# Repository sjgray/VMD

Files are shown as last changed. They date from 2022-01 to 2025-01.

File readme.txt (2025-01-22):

VMD - Visual Memory Display - Steve J. Gray
===========================

INTRO

This is a fun little project, probably not with many practical uses,
other than being a cool blinking lights display. On the CBM-Hackers
forum Leif Bloomquist proposed the idea of adding interesting lights
inside his transparent C64 case to show computer activity. I came up
with an idea to use a large 16x16 LED matrix wired to the address
bus using some 4-to-16 decoders. Jim Brain liked the idea and said
he would build it, and he did. He came up with a circuit which he
demonstrated at the VCF-MW show in September 2016. I am attempting to
design a PCB or two to implement this internally.

STATUS

The project is functional. This version is the initial proof of concept
design, not created for any specific LED matrix modules. You will need
to look at the datasheet for your module and figure out how to connect
them. The COL pins are the + (anode) of the LED and the ROW are the cathode.

I was hoping to improve the design, and/or adapt it to some specific LED
module to make connections easier, but the project seems to have been
put on the back-burner. So, I am releasing the schematics and gerbers
as-is in the hopes that it might be useful.

FOLDERS

VMD.......... Main Visual Memory Display board
CPU-Tap...... 6502/6510 breakout board with VMD connectors.
		tabs can be removed if you just need the breakout pins.
MemoryMaps... Memory Maps for CBM computers using 16x16 matrix organization

WEB

You can find more info on the project webpage:

http://www.cbmsteve.ca/
http://www.cbmsteve.ca/vmd/index.html

Steve

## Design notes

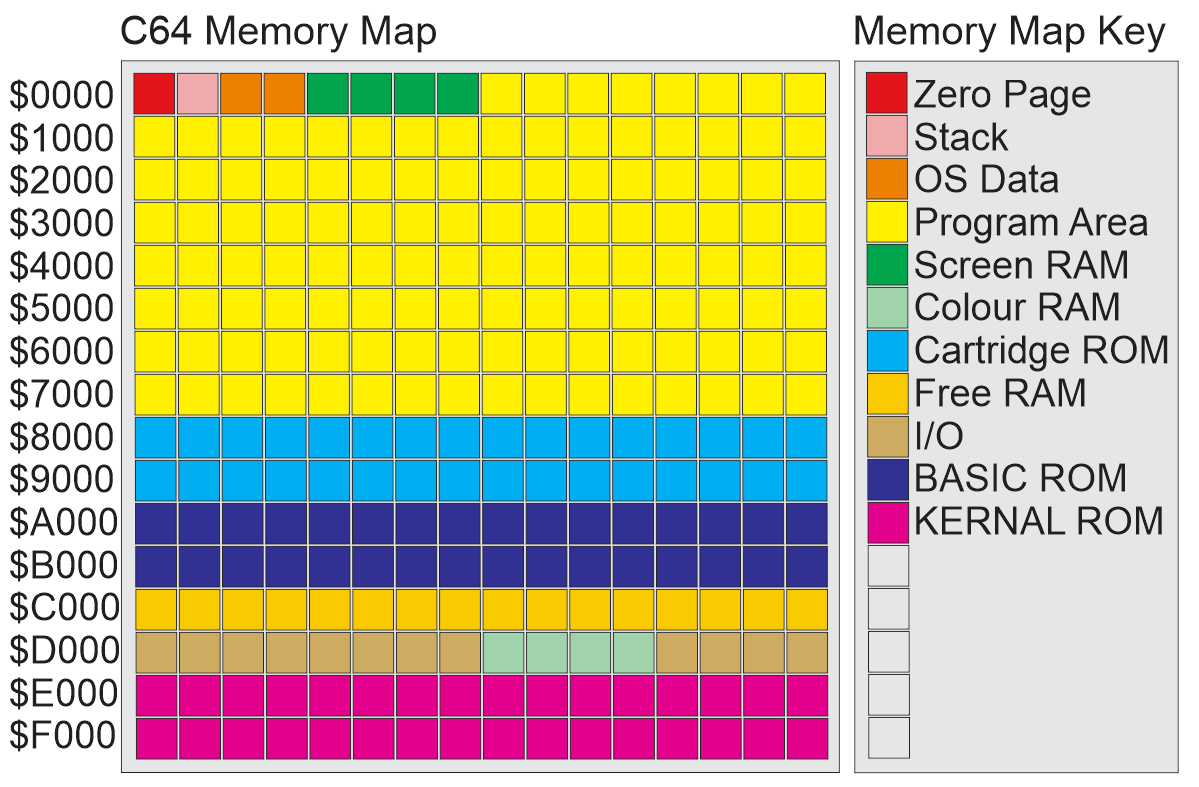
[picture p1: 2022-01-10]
MemoryMaps/vmd-map-c64.png

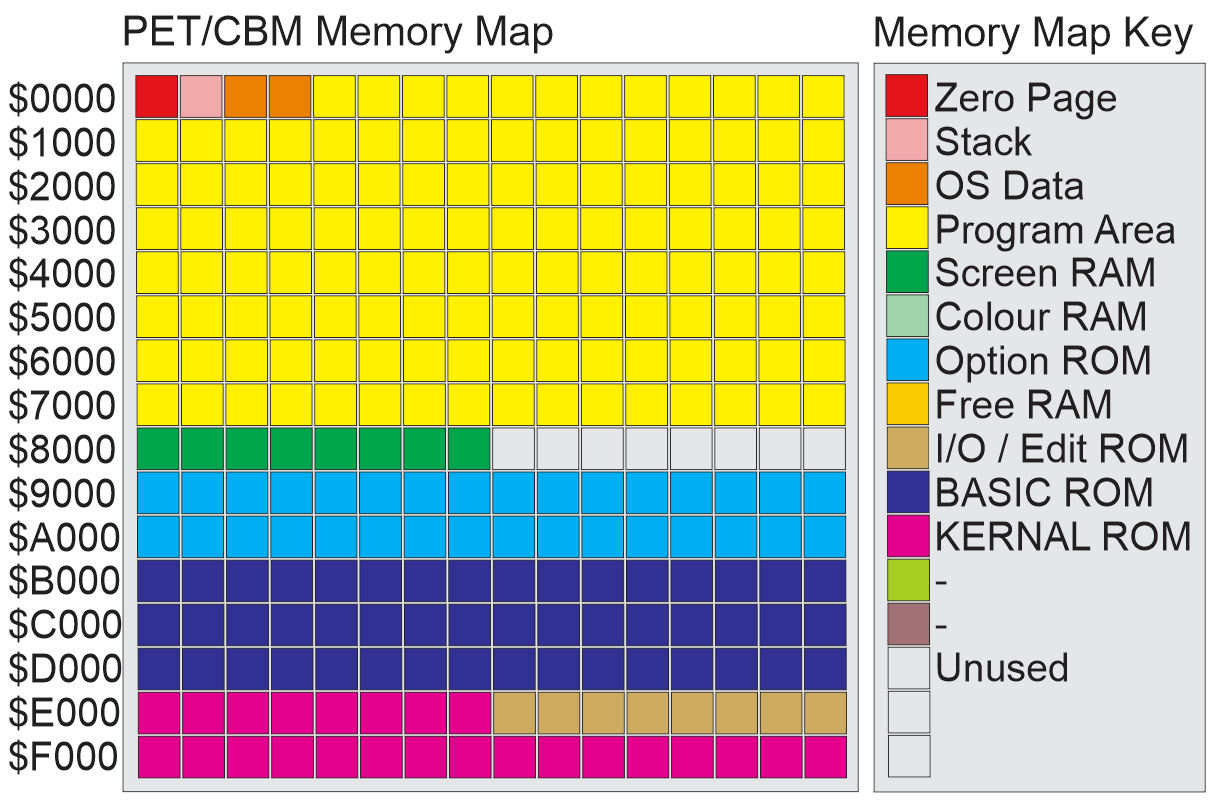
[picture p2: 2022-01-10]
MemoryMaps/vmd-map-pet.png

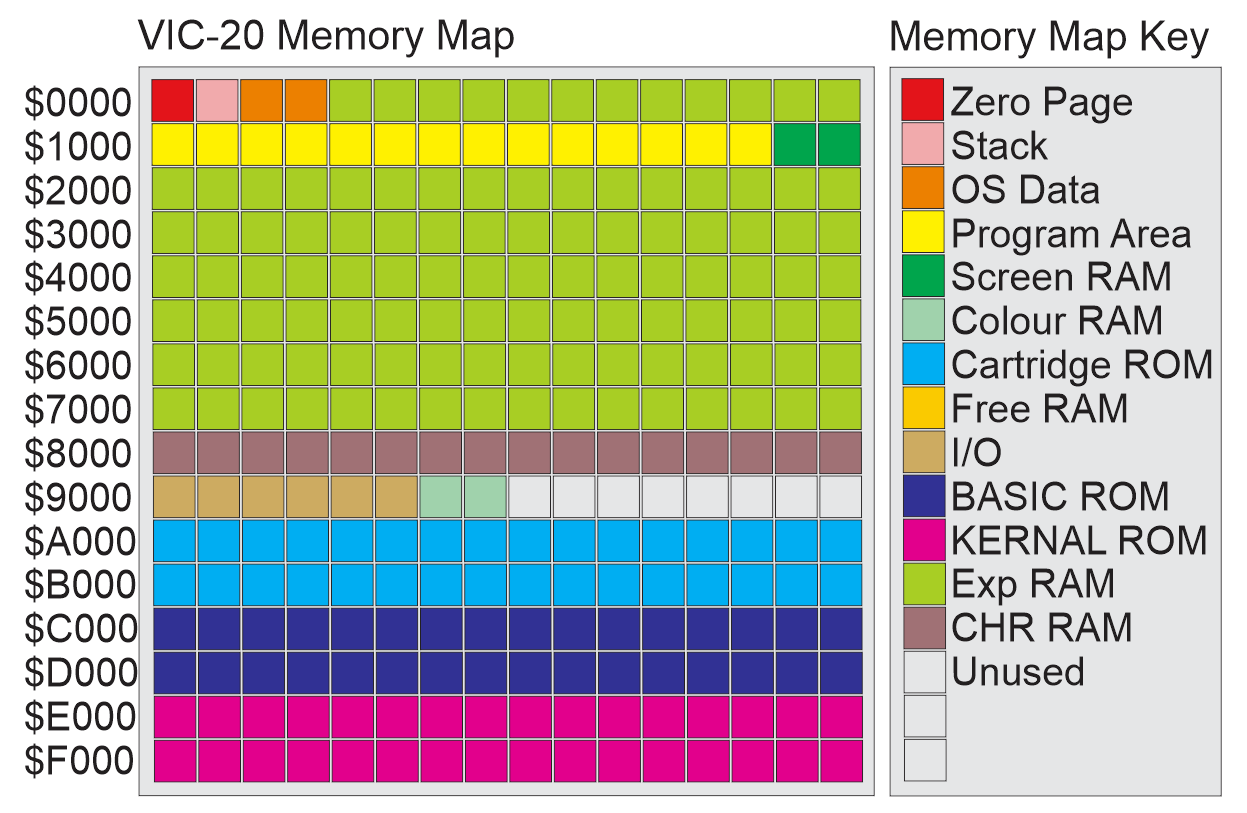
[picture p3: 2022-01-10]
MemoryMaps/vmd-map-vic20.png

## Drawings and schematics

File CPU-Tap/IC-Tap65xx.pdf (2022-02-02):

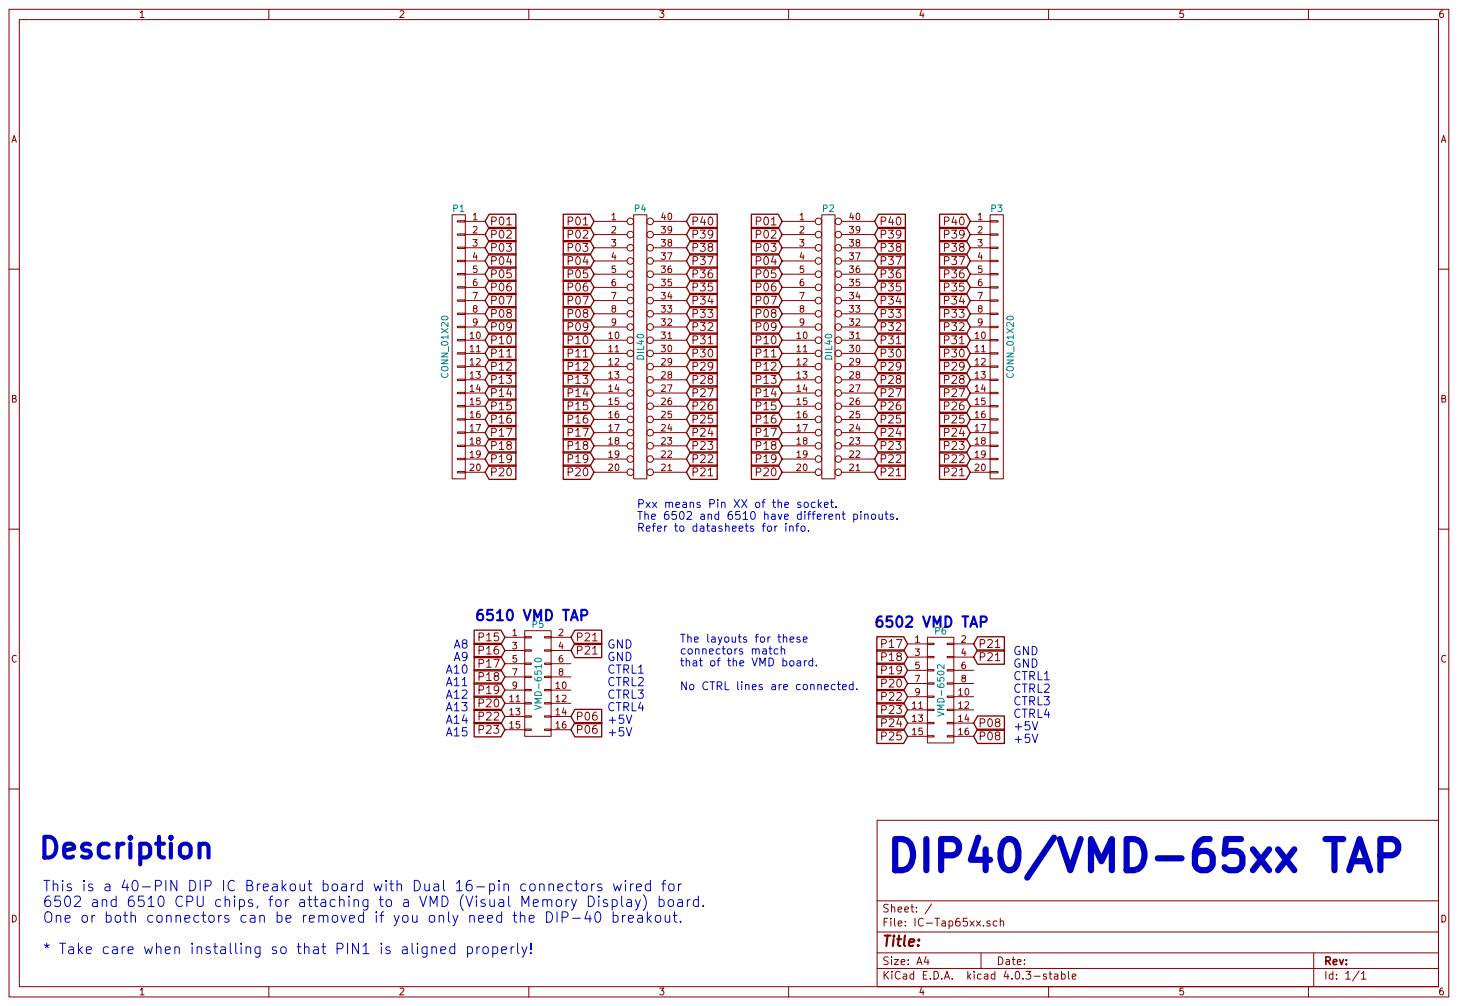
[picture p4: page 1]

P21 P08 Pxx means Pin XX of the socket. The 6502 and 6510 have different pinouts. Refer to datasheets for info. The layouts for these

connectors match
that of the VMD board. No CTRL lines are connected.

This is a 40-PIN DIP IC Breakout board with Dual 16-pin connectors wired for
6502 and 6510 CPU chips, for attaching to a VMD (Visual Memory Display) board.
One or both connectors can be removed if you only need the DIP-40 breakout.
* Take care when installing so that PIN1 is aligned properly!

File: IC-Tap65xx.sch Sheet: /
Id: 1/1 Title:

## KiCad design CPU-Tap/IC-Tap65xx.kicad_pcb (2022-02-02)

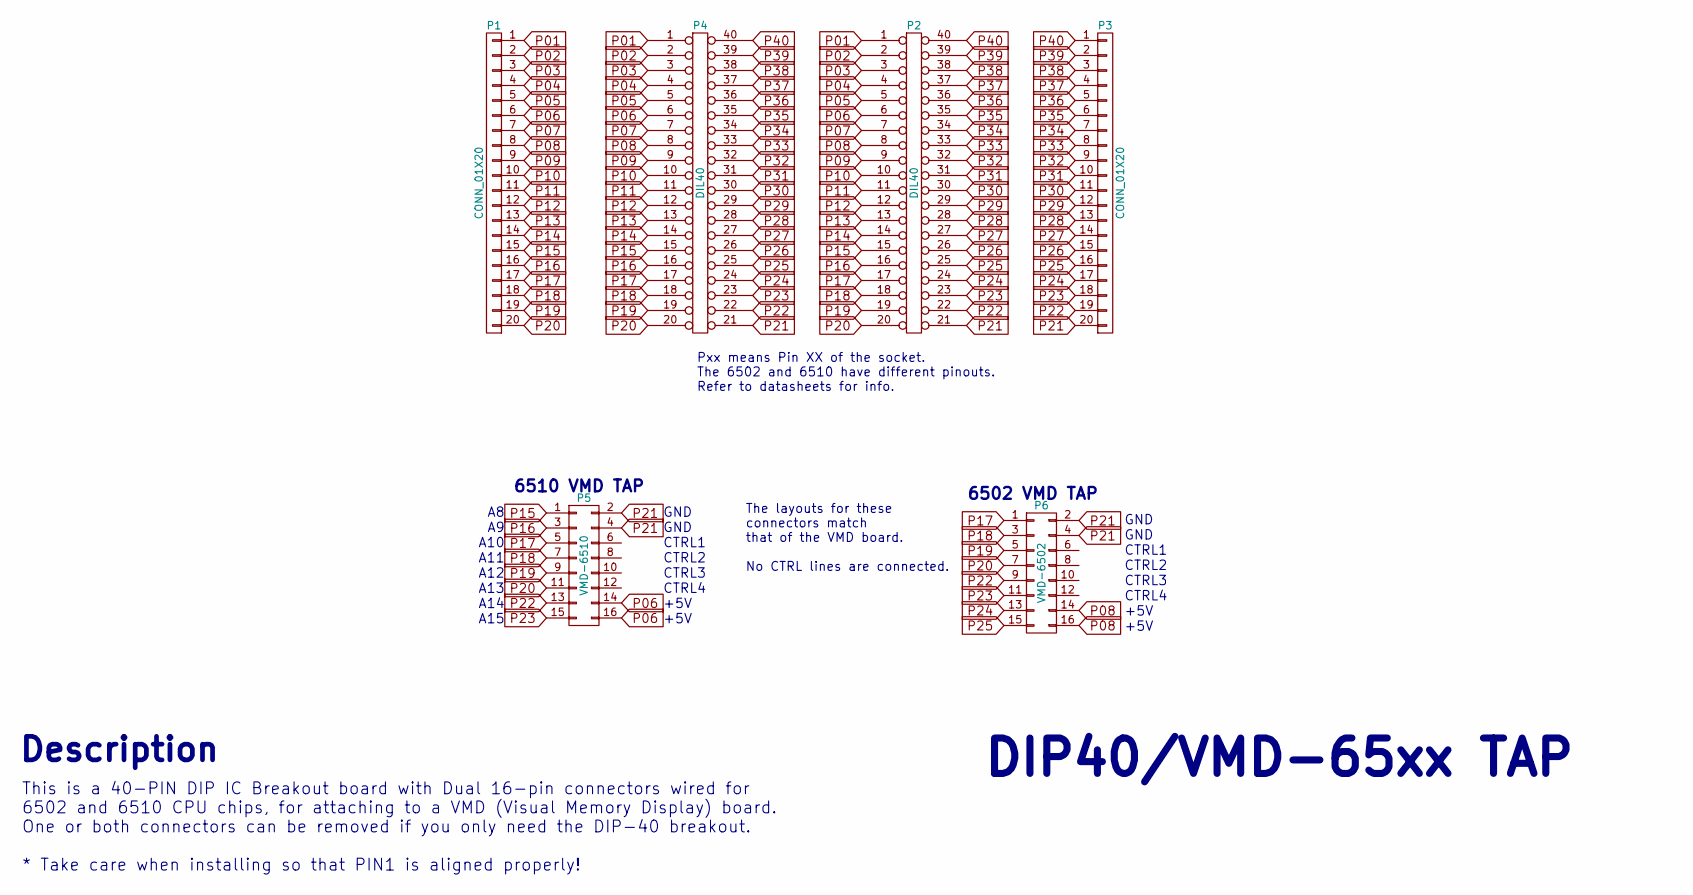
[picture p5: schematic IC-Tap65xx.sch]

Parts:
P1, P3: CONN_01X20; Pin_Header_Straight_1x20
P2, P4: DIL40; DIP-40_W15.24mm_LongPads
P5: VMD-6510; Pin_Header_Straight_2x08
P6: VMD-6502; Pin_Header_Straight_2x08

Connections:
P01: P1.1, P2.1, P4.1
P02: P1.2, P2.2, P4.2
P03: P1.3, P2.3, P4.3
P04: P1.4, P2.4, P4.4
P05: P1.5, P2.5, P4.5
P06: P1.6, P2.6, P4.6, P5.14, P5.16
P07: P1.7, P2.7, P4.7
P08: P1.8, P2.8, P4.8, P6.14, P6.16
P09: P1.9, P2.9, P4.9
P10: P1.10, P2.10, P4.10
P11: P1.11, P2.11, P4.11
P12: P1.12, P2.12, P4.12
P13: P1.13, P2.13, P4.13
P14: P1.14, P2.14, P4.14
P15: P1.15, P2.15, P4.15, P5.1
P16: P1.16, P2.16, P4.16, P5.3
P17: P1.17, P2.17, P4.17, P5.5, P6.1
P18: P1.18, P2.18, P4.18, P5.7, P6.3
P19: P1.19, P2.19, P4.19, P5.9, P6.5
P20: P1.20, P2.20, P4.20, P5.11, P6.7
P21: P2.21, P3.20, P4.21, P5.2, P5.4, P6.2, P6.4
P22: P2.22, P3.19, P4.22, P5.13, P6.9
P23: P2.23, P3.18, P4.23, P5.15, P6.11
P24: P2.24, P3.17, P4.24, P6.13
P25: P2.25, P3.16, P4.25, P6.15
P26: P2.26, P3.15, P4.26
P27: P2.27, P3.14, P4.27
P28: P2.28, P3.13, P4.28
P29: P2.29, P3.12, P4.29
P30: P2.30, P3.11, P4.30
P31: P2.31, P3.10, P4.31
P32: P2.32, P3.9, P4.32
P33: P2.33, P3.8, P4.33
P34: P2.34, P3.7, P4.34
P35: P2.35, P3.6, P4.35
P36: P2.36, P3.5, P4.36
P37: P2.37, P3.4, P4.37
P38: P2.38, P3.3, P4.38
P39: P2.39, P3.2, P4.39
P40: P2.40, P3.1, P4.40

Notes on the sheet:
A8 A9 A10 A11 A12 A13 A14 A15
GND GND CTRL1 CTRL2 CTRL3 CTRL4 +5V +5V
6510 VMD TAP
6502 VMD TAP
Pxx means Pin XX of the socket. The 6502 and 6510 have different pinouts. Refer to datasheets for info.
The layouts for these connectors match that of the VMD board. No CTRL lines are connected.
DIP40/VMD-65xx TAP
This is a 40-PIN DIP IC Breakout board with Dual 16-pin connectors wired for 6502 and 6510 CPU chips, for attaching to a VMD (Visual Memory Display) board. One or both connectors can be removed if you only need the DIP-40 breakout. * Take care when installing so that PIN1 is aligned properly!
Description

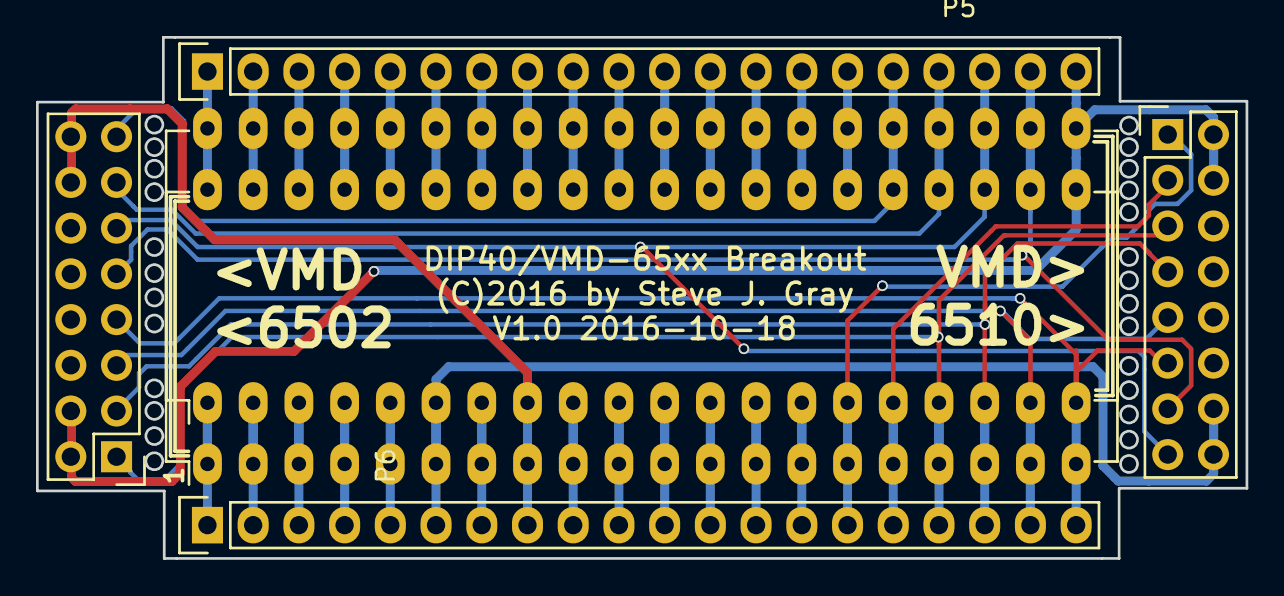
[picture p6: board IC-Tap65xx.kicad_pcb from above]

Board: 2 copper layers, 67.2 x 29.0 mm, 6 parts (0 on the bottom side), 40 nets.

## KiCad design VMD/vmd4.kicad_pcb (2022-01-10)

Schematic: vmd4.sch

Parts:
C1, C2, C3, C4, C5, C6, C7, C8, C9: .1; C_Disc_D3_P2.5
P1: CONN_02X08; Pin_Header_Straight_2x08
P2: CONN_02X04; Pin_Header_Straight_2x04
P3, P4: ROW 0-7; Pin_Header_Straight_1x08
P5, P6: ROW 8-15; Pin_Header_Straight_1x08
P7, P8, P9, P10: COL 0-7; Pin_Header_Straight_1x08
P11: CONN_01X02; Pin_Header_Straight_1x02
R1, R2, R3, R4: R_Small; Resistor_Horizontal_RM7mm
RP1, RP2: 220 ohm; DIP-16_W7.62mm_LongPads
S1: SW_DIP_x4; SW_DIP_x4_Slide
U1, U3, U5, U7: 74LS138; DIP-16_W7.62mm_LongPads
U2, U4, U6, U8: 74LS541; DIP-20_W7.62mm_LongPads
U9: 74LS86; DIP-14_W7.62mm_LongPads

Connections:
5V: C1.1, C2.1, C3.1, C4.1, C5.1, C6.1, C7.1, C8.1, C9.1, P1.14, P1.16, P11.1, R1.1, R2.1, R3.1, R4.1, U1.6 (E3), U1.16 (VCC), U2.20 (VCC), U3.16 (VCC), U4.20 (VCC), U5.6 (E3), U5.16 (VCC), U6.20 (VCC), U7.16 (VCC), U8.20 (VCC), U9.14 (VCC)
A8: P1.1, U5.1 (A0), U7.1 (A0)
A9: P1.3, U5.2 (A1), U7.2 (A1)
A10: P1.5, U5.3 (A2), U7.3 (A2)
A11: P1.7, U5.5 (E2), U7.6 (E3)
A12: P1.9, U1.1 (A0), U3.1 (A0)
A13: P1.11, U1.2 (A1), U3.2 (A1)
A14: P1.13, U1.3 (A2), U3.3 (A2)
A15: P1.15, U1.5 (E2), U3.6 (E3)
C0: P7.1, P8.1, RP1.16 (R1)
C1: P7.2, P8.2, RP1.15 (R2)
C2: P7.3, P8.3, RP1.14 (R3)
C3: P7.4, P8.4, RP1.13 (R4)
C4: P7.5, P8.5, RP1.12 (R5)
C5: P7.6, P8.6, RP1.11 (R6)
C6: P7.7, P8.7, RP1.10 (R7)
C7: P7.8, P8.8, RP1.9 (R8)
C8: P9.1, P10.1, RP2.16 (R1)
C9: P9.2, P10.2, RP2.15 (R2)
C10: P9.3, P10.3, RP2.14 (R3)
C11: P9.4, P10.4, RP2.13 (R4)
C12: P9.5, P10.5, RP2.12 (R5)
C13: P9.6, P10.6, RP2.11 (R6)
C14: P9.7, P10.7, RP2.10 (R7)
C15: P9.8, P10.8, RP2.9 (R8)
CTRL1: P1.6, P2.2, U9.2 (IN2)
CTRL2: P1.8, P2.4, U9.5 (IN2)
CTRL3: P1.10, P2.6, U9.10 (IN2)
CTRL4: P1.12, P2.8, U9.13 (IN2)
G1: U2.1 (G1), U4.1 (G1), U9.3 (OUT)
G2: U2.19 (G2), U4.19 (G2), U9.6 (OUT)
G3: U6.1 (G1), U8.1 (G1), U9.8 (OUT)
G4: U6.19 (G2), U8.19 (G2), U9.11 (OUT)
GND: C1.2, C2.2, C3.2, C4.2, C5.2, C6.2, C7.2, C8.2, C9.2, P1.2, P1.4, P2.1, P2.3, P2.5, P2.7, P11.2, S1.1, S1.2, S1.3, S1.4, U1.4 (E1), U1.8 (GND), U2.10 (GND), U3.4 (E1), U3.5 (E2), U3.8 (GND), U4.10 (GND), U5.4 (E1), U5.8 (GND), U6.10 (GND), U7.4 (E1), U7.5 (E2), U7.8 (GND), U8.10 (GND), U9.7 (GND)
unnamed: R1.2, S1.5, U9.12 (IN1)
unnamed: R2.2, S1.6, U9.9 (IN1)
unnamed: R3.2, S1.7, U9.4 (IN1)
unnamed: R4.2, S1.8, U9.1 (IN1)
unnamed: RP1.1, U6.18 (Y0)
unnamed: RP1.2, U6.17 (Y1)
unnamed: RP1.3, U6.16 (Y2)
unnamed: RP1.4, U6.15 (Y3)
unnamed: RP1.5, U6.14 (Y4)
unnamed: RP1.6, U6.13 (Y5)
unnamed: RP1.7, U6.12 (Y6)
unnamed: RP1.8, U6.11 (Y7)
unnamed: RP2.1, U8.18 (Y0)
unnamed: RP2.2, U8.17 (Y1)
unnamed: RP2.3, U8.16 (Y2)
unnamed: RP2.4, U8.15 (Y3)
unnamed: RP2.5, U8.14 (Y4)
unnamed: RP2.6, U8.13 (Y5)
unnamed: RP2.7, U8.12 (Y6)
unnamed: RP2.8, U8.11 (Y7)
unnamed: U1.7 (O7), U2.9 (A7)
unnamed: U1.9 (O6), U2.8 (A6)
unnamed: U1.10 (O5), U2.7 (A5)
unnamed: U1.11 (O4), U2.6 (A4)
unnamed: U1.12 (O3), U2.5 (A3)
unnamed: U1.13 (O2), U2.4 (A2)
unnamed: U1.14 (O1), U2.3 (A1)
unnamed: U1.15 (O0), U2.2 (A0)
unnamed: U3.7 (O7), U4.9 (A7)
unnamed: U3.9 (O6), U4.8 (A6)
unnamed: U3.10 (O5), U4.7 (A5)
unnamed: U3.11 (O4), U4.6 (A4)
unnamed: U3.12 (O3), U4.5 (A3)
unnamed: U3.13 (O2), U4.4 (A2)
unnamed: U3.14 (O1), U4.3 (A1)
unnamed: U3.15 (O0), U4.2 (A0)
unnamed: U5.7 (O7), U6.9 (A7)
unnamed: U5.9 (O6), U6.8 (A6)
unnamed: U5.10 (O5), U6.7 (A5)
unnamed: U5.11 (O4), U6.6 (A4)
unnamed: U5.12 (O3), U6.5 (A3)
unnamed: U5.13 (O2), U6.4 (A2)
unnamed: U5.14 (O1), U6.3 (A1)
unnamed: U5.15 (O0), U6.2 (A0)
unnamed: U7.7 (O7), U8.9 (A7)
unnamed: U7.9 (O6), U8.8 (A6)
unnamed: U7.10 (O5), U8.7 (A5)
unnamed: U7.11 (O4), U8.6 (A4)
unnamed: U7.12 (O3), U8.5 (A3)
unnamed: U7.13 (O2), U8.4 (A2)
unnamed: U7.14 (O1), U8.3 (A1)
unnamed: U7.15 (O0), U8.2 (A0)
R0: P3.1, P4.1, U2.18 (Y0)
R1: P3.2, P4.2, U2.17 (Y1)
R2: P3.3, P4.3, U2.16 (Y2)
R3: P3.4, P4.4, U2.15 (Y3)
R4: P3.5, P4.5, U2.14 (Y4)
R5: P3.6, P4.6, U2.13 (Y5)
R6: P3.7, P4.7, U2.12 (Y6)
R7: P3.8, P4.8, U2.11 (Y7)
R8: P5.1, P6.1, U4.18 (Y0)
R9: P5.2, P6.2, U4.17 (Y1)
R10: P5.3, P6.3, U4.16 (Y2)
R11: P5.4, P6.4, U4.15 (Y3)
R12: P5.5, P6.5, U4.14 (Y4)
R13: P5.6, P6.6, U4.13 (Y5)
R14: P5.7, P6.7, U4.12 (Y6)
R15: P5.8, P6.8, U4.11 (Y7)

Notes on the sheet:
LED VMD - Visual Memory Display
There are 4 Control lines - CTRL1 to CTRL4. Use DIP Switch to select if control lines trigger on HI or LO state. Unused control lines should be tied to GND or 5V and the matching DIP Switch line set accordingly.
Both "G" lines must be HI to enable output
74LS540
A15=HI >
A15=LO >
A11=LO >
A11=HI >
Based on an idea by Leif Bloomquist and Circuit by Jim Brain
There will be a companion CPU "tap" PCB with this same pinout.
On an 8-bit CPU there are 16 Address lines. The top 8 select one of 256 pages of memory, each containing 256 bytes. Of the top 8 bits we use 4 to select a ROW and 4 to select a COL. Each set of 4 lines is decoded to a single output by two 3-to-8 decoder chips. These are fed to a buffer chip that ca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
or use individual 220 ohm resitors
Circuit Description
Control
Decode
LED Drivers
LED Connectors
Unused CTRL
Optional Power
Jumper unused CTRL lines to GND
Can be used to power board from external 5V supply
Bypass caps

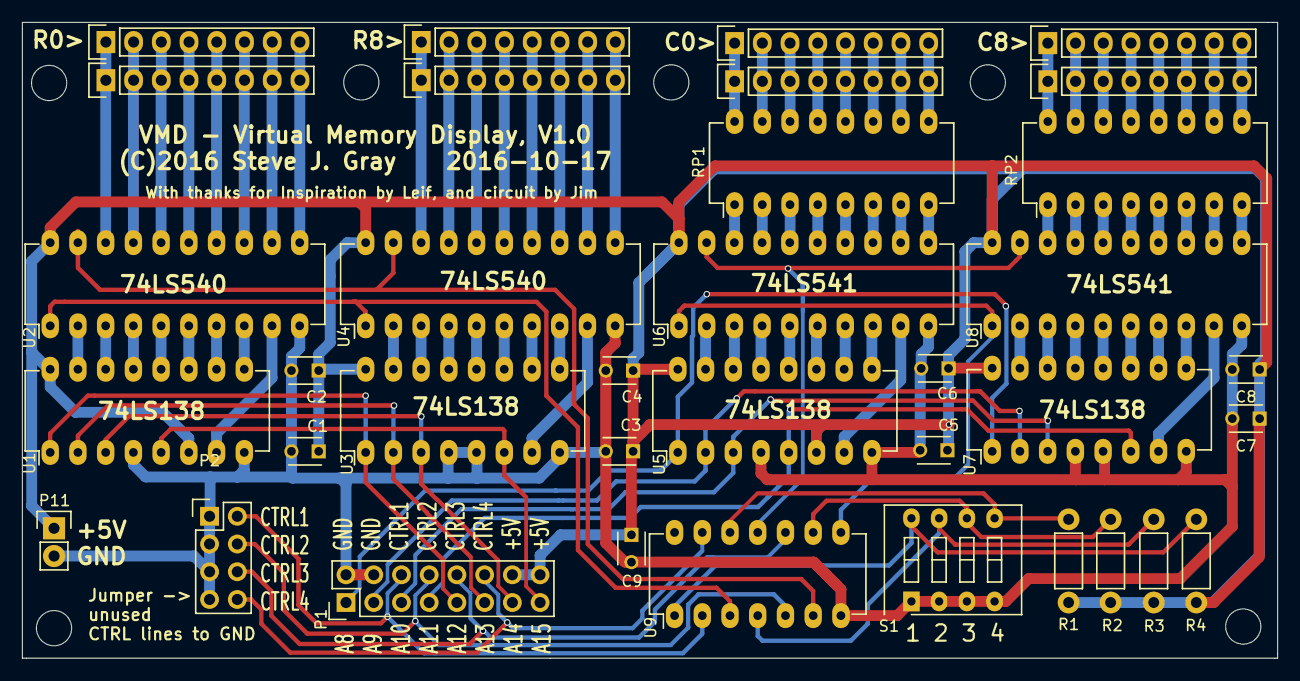
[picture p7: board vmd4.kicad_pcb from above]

Board: 2 copper layers, 115.0 x 58.2 mm, 36 parts (0 on the bottom side), 102 nets.

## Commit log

2022-01-10 Initial Commit.
    This is the initial working design Kicad files and Gerbers. The design
    is functional as a proof-of-concept. It is possible to modify the
    design with specific LED modules on the board if that is desired, but
    left up to you.
    [vmd4.kicad_pcb, vmd4.sch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]
2022-02-02 Add CPU-Tap. Folder re-org
    Added CPU-Tap/breakout board for 6502/6510 processors. Move VMD board
    into folder.
    [IC-Tap65xx.kicad_pcb, IC-Tap65xx.sch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]

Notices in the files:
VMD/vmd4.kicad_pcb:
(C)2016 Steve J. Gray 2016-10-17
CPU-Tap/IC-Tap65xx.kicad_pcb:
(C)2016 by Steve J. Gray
